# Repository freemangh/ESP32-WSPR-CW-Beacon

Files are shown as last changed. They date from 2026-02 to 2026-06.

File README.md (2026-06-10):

# ESP32 WSPR/FT8/CW Beacon

A standalone HF Beacon (WSPR, FT8 & CW) running on an ESP32.
It uses the ESP32's internal APLL (Audio PLL) clocking the I2S bit clock (BCK), routed through the GPIO matrix to generate RF directly on a GPIO pin. Because the APLL's native tuning step (~19 Hz at 14 MHz) is far coarser than the WSPR/FT8 tone spacing, a background task dithers the APLL fractional divider (software fractional-N synthesis) so the average frequency lands exactly on the requested tone.

## Features
- **WSPR Beacon**: Transmits standard WSPR Type 1 messages on the 20m band (14.0956 MHz).
- **FT8 Beacon**: Transmits `CQ CALL GRID` on 14.074 MHz in four consecutive 15 s slots.
- **CW Identification**: Transmits Morse code ID (Callsign + Grid) once per cycle.
- **Precision Timing**: Syncs via NTP over WiFi to ensure perfect WSPR/FT8 slot timing.
- **Frequency Calibration**: PPM correction constant to compensate crystal error.
- **OLED Display**: Shows current status, time, and transmission progress.
- **Direct RF Output**: Generates RF directly from a GPIO pin (default GPIO 27).
- **Power Output**: Approx. **10-15 mW (10-12 dBm)** direct drive.

## Transmission Schedule
The beacon runs a fixed 4-minute cycle, aligned to UTC:

| Minute (mod 4) | Mode | Start |
|---|---|---|
| 0–1 | WSPR (110.6 s) | :01 |
| 2 | FT8 (4 slots)  | :01, :16, :31, :46 |
| 3 | CW ID | :10 |

## Hardware Required
1. **ESP32 Development Board** (ESP32-WROOM-32 or similar)
2. **SSD1306 OLED Display** (I2C)
3. **Low Pass Filter (LPF)** for 20m Band (Critical for harmonic suppression)
4. **Antenna** (tuned for 14 MHz)

## Wiring

| ESP32 Pin | Component | Function |
|---|---|---|
| **GPIO 27**| **RF Output** | Signal to LPF -> Antenna |
| GPIO 21 | OLED SDA  | I2C Data |
| GPIO 22 | OLED SCL  | I2C Clock|
| 5V / 3V3  | VCC | Power |
| GND | GND | Ground |

**Note**: The RF Output pin can be changed in `src/Config.h`.

## Optional Power Amplifier (Boost to ~250mW)
To increase power from ~10mW to ~250mW (24dBm), use a simple BS170 MOSFET amplifier.

**Schematic:**
```mermaid
graph LR
    GPIO((GPIO 27)) -- 100R --- G
    G -- 10k --- GND
    
    subgraph BS170
    G(Gate)
    D(Drain)
    S(Source)
    end
    
    S --- GND((GND))
    VCC((+5V)) -- 10uH Choke --- D
    D -- 100nF --- LPF((To LPF))
```
- **Q1**: BS170 or 2N7000 MOSFET
- **Choke**: 10uH RF Choke (RFC)
- **C_Block**: 100nF Ceramic
- **R_Gate**: 100 ohm (Series), 10k (Pulldown)

## Low Pass Filter (LPF)
The output is a square wave. You **MUST** use a Low Pass Filter before connecting an antenna to prevent interference on higher harmonics.

**Schematic (20m / 14MHz):**
```mermaid
graph LR
    IN((RF IN)) -- L1 --- J1
    J1 -- L2 --- J2
    J2 -- L3 --- ANT((ANT))
    
    IN -- C1 --- G1((GND))
    J1 -- C2 --- G2((GND))
    J2 -- C3 --- G3((GND))
    ANT -- C4 --- G4((GND))
```
- **L1, L3**: 12 turns (~0.6 uH) on T37-6
- **L2**: 14 turns (~0.7 uH) on T37-6
- **C1, C4**: 470 pF
- **C2, C3**: 1000 pF

## Configuration
`src/Config.h` is gitignored (it contains your WiFi credentials). Create it from the template and configure your station:
```bash
cp src/Config.h.example src/Config.h
```
```cpp
#define WIFI_SSID "YOUR_SSID"
#define WIFI_PASS "YOUR_PASSWORD"
#define CALLSIGN "N0CALL"          // Your Callsign
#define GRID_LOCATOR "AA00aa"      // Your Grid Square
#define FREQ_CORRECTION_PPM 0.0    // Crystal error correction (see below)
#define RF_PIN 27                  // Output Pin
```

### Frequency Calibration
Devboard crystals are typically off by 10–20 ppm, which is 150–300 Hz at 14 MHz — enough to land outside the 200 Hz WSPR window. Measure the actual carrier with an SDR during a transmission and set the correction:

```
measured 14095750 Hz vs requested 14095600 Hz -> +150 Hz error
FREQ_CORRECTION_PPM = -offset_hz / freq_mhz = -150.0 / 14.0956 = -10.6
```

## Build & Upload
This project uses **PlatformIO**.

1. Clone the repository.
2. Open in VSCode with PlatformIO extension.
3. Create and edit `src/Config.h` (see Configuration).
4. Run **Upload**:
   ```bash
   pio run -t upload
   ```
5. Monitor output:
   ```bash
   pio device monitor
   ```

## Verifying with an SDR
- Tune an SDR (e.g. HackRF with gqrx/SDR++) to 14.0956 MHz in USB/CW mode and watch the waterfall during minutes 0–1 of the cycle. Expect the carrier within a few hundred Hz of nominal until you calibrate `FREQ_CORRECTION_PPM`.
- To verify decodes, feed the SDR audio into WSJT-X (WSPR mode on 20m, or FT8 during minute 2).
- **Never connect the beacon output to the SDR input with a cable directly**: +10 dBm is at the absolute maximum input rating of a HackRF. Receive over the air, or use at least 30 dB of attenuation.
- Note: VHF/UHF FM handhelds (e.g. AnyTone AT-D878UV) cannot receive this beacon — 14 MHz is outside their frequency range, and an FM receiver cannot demodulate a CW carrier anyway.

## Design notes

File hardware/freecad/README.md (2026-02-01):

# FreeCAD Beacon Assembly

This directory contains resources to generate a 3D Assembly of the ESP32 Beacon in FreeCAD.

## How to use
1. Open **FreeCAD**.
2. Go to **View -> Panels -> Python Console** (Ensure it is visible).
3. Open the `beacon_assembly.py` file in a text editor.
4. Copy the entire content of `beacon_assembly.py`.
5. Paste it into the **Python Console** in FreeCAD and press Enter.

## Result
The script will generate a new document named `Beacon_Assembly` containing:
- The PCB Substrate (Green)
- ESP32 Development Board (Generic representation)
- OLED Display
- SMA Connector
- LPF Components (Inductors and Capacitors)

You can then export this as STEP or STL for enclosure design.

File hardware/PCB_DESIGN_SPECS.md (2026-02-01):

# PCB Design Specifications - ESP32 WSPR Beacon

## 1. Schematic Connections

### Main Controller (ESP32 Dev Board)
- **3V3**: Connect to Display VCC.
- **GND**: Connect to Display GND, LPF Ground, RF Connector Ground.
- **GPIO 21 (SDA)**: Connect to Display SDA.
- **GPIO 22 (SCL)**: Connect to Display SCL.
- **GPIO 27**: **RF SOURCE**. Connect to LPF Input.

### Low Pass Filter (LPF) Network
*Note: Layout should be linear (Input -> L1 -> L2 -> L3 -> Output)*
1. **Input Node**:
   - Connect **ESP32 GPIO 27**.
   - Connect **C1 (470pF)** to GND.
   - Connect **L1 (0.6uH)** Pin 1.
2. **Node A (Between L1/L2)**:
   - Connect **L1** Pin 2.
   - Connect **C2 (1000pF)** to GND.
   - Connect **L2 (0.7uH)** Pin 1.
3. **Node B (Between L2/L3)**:
   - Connect **L2** Pin 2.
   - Connect **C3 (1000pF)** to GND.
   - Connect **L3 (0.6uH)** Pin 1.
4. **Output Node**:
   - Connect **L3** Pin 2.
   - Connect **C4 (470pF)** to GND.
   - Connect **RF Connector** Center Pin.

### Peripherals
- **OLED Display**:
  - VCC -> 3V3
  - GND -> GND
  - SDA -> GPIO 21
  - SCL -> GPIO 22

## 2. Layout Guidelines
1. **RF Trace**: Keep the trace from GPIO 27 to LPF and LPF to Antenna short and thick (e.g., 0.5mm+).
2. **Ground Plane**: Use a solid Ground Pour on bottom (and top if possible). Stitch them with vias.
3. **LPF**:
   - Place Capacitors (C1-C4) close to the inductors.
   - Ensure specific Ground Vias for each capacitor component to the ground plane.
   - Keep the LPF components (Inductors) slightly spaced to avoid magnetic coupling (or place at 90 degrees if very close).
4. **Antenna Connector**: Place at board edge. Ensure good grounding on the shield pins.

## 3. Mounting
- Add M3 mounting holes at corners.
- Dimensions recommended: 70mm x 50mm (Approx).

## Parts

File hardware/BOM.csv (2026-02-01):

Item | Reference | Qty | Description | Value | Footprint
1 | U1 | 1 | ESP32 Development Board | ESP32-WROOM-32 | Module:ESP32_DevBoard
2 | DSP1 | 1 | OLED Display I2C | SSD1306 0.96 inch | Connector_PinHeader_2.54mm:PinHeader_1x04_P2.54mm_Vertical
3 | J1 | 1 | RF Output Connector | SMA / BNC | Connector_Coaxial:SMA_Amphenol_132203_Vertical
4 | C1,C4 | 2 | Ceramic Capacitor (C0G/NP0) | 470pF / 50V | Capacitor_SMD:C_0805_2012Metric
5 | C2,C3 | 2 | Ceramic Capacitor (C0G/NP0) | 1000pF / 50V | Capacitor_SMD:C_0805_2012Metric
6 | L1,L3 | 2 | Inductor (Toroid T37-6) | 0.6uH (12 turns) | Inductor_THT:L_Toroid_Vertical_L10.0mm_W5.0mm_P5.08mm
7 | L2 | 1 | Inductor (Toroid T37-6) | 0.7uH (14 turns) | Inductor_THT:L_Toroid_Vertical_L10.0mm_W5.0mm_P5.08mm
8 | J2 | 1 | Power Connector (Optional if USB used) | 2-pin Screw Terminal | Connector_Phoenix_MC:PhoenixContact_MC_1,5_2-G-3.81_1x02_P3.81mm_Horizontal

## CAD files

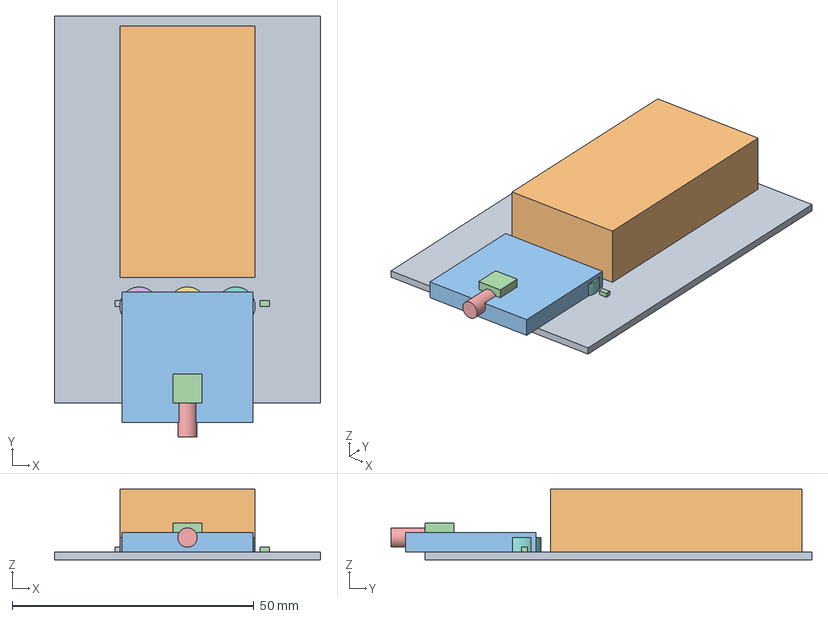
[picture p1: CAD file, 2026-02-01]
hardware/freecad/Beacon_Assembly.FCStd
55.0 x 87.0 x 14.6 mm
PCB
ESP32
OLED
SMA_Body
SMA_Pin
L1
L2
L3
C1
C2
C3
C4

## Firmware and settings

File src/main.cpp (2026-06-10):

#include <Adafruit_GFX.h>
#include <Adafruit_SSD1306.h>
#include <Arduino.h>
#include <JTEncode.h>
#include <WiFi.h>
#include <Wire.h>
#include <time.h>

#include "Config.h"
#include "Radio.h"

// Objects
Adafruit_SSD1306 display(SCREEN_WIDTH, SCREEN_HEIGHT, &Wire, OLED_RESET);
JTEncode jtEncode;

// Global State
bool wifiConnected = false;
bool timeSynced = false;
bool isTransmittingWSPR = false;
bool isTransmittingCW = false;
bool isTransmittingFT8 = false;

// WSPR State
uint8_t tx_buffer[255]; // Encoded symbols (values 0-3)
int symbol_count = 0;
int current_symbol_index = 0;
unsigned long time_last_symbol = 0;
const unsigned long WSPR_SYMBOL_DURATION_US = 682667;
const double WSPR_TONE_SPACING = 1.4648;

// FT8 State
uint8_t tx_buffer_ft8[79];
int ft8_symbol_count = 0;
int current_ft8_index = 0;
unsigned long time_last_ft8 = 0;
const unsigned long FT8_SYMBOL_DURATION_US = 160000;
const double FT8_TONE_SPACING_VAL = 6.25;

// CW State
const char *cw_message = CALLSIGN " " GRID_LOCATOR;
int cw_char_index = 0;
int cw_element_index = 0; // Index within the morse string for a char
unsigned long cw_last_element_time = 0;
const int CW_WPM = 20;
const int CW_DOT_MS = 1200 / CW_WPM;
bool cw_tone_on = false;
String current_morse_char = "";

// Morse Code Table (Simple A-Z, 0-9)
const char *morse_table[] = {
    ".-",    // A
    "-...",  // B
    "-.-.",  // C
    "-..",   // D
    ".",     // E
    "..-.",  // F
    "--.",   // G
    "....",  // H
    "..",    // I
    ".---",  // J
    "-.-",   // K
    ".-..",  // L
    "--",    // M
    "-.",    // N
    "---",   // O
    ".--.",  // P
    "--.-",  // Q
    ".-.",   // R
    "...",   // S
    "-",     // T
    "..-",   // U
    "...-",  // V
    ".--",   // W
    "-..-",  // X
    "-.--",  // Y
    "--..",  // Z
    "-----", // 0
    ".----", // 1
    "..---", // 2
    "...--", // 3
    "....-", // 4
    ".....", // 5
    "-....", // 6
    "--...", // 7
    "---..", // 8
    "----."  // 9
};

const char *getMorse(char c) {
  if (c >= 'a' && c <= 'z')
    c -= 32; // To Upper
  if (c >= 'A' && c <= 'Z')
    return morse_table[c - 'A'];
  if (c >= '0' && c <= '9')
    return morse_table[c - '0' + 26];
  return ""; // Space or unknown
}

// Epoch values below this mean the system clock has not been set yet
const time_t TIME_VALID_EPOCH = 1600000000; // 2020-09-13

String formatUTC() {
  time_t now = time(nullptr);
  struct tm tmv;
  gmtime_r(&now, &tmv);
  char buf[20];
  snprintf(buf, sizeof(buf), "%04d-%02d-%02d %02d:%02d:%02d",
           tmv.tm_year + 1900, tmv.tm_mon + 1, tmv.tm_mday, tmv.tm_hour,
           tmv.tm_min, tmv.tm_sec);
  return String(buf);
}

void setupDisplay() {
  Wire.begin(I2C_SDA, I2C_SCL);
  if (!display.begin(SSD1306_SWITCHCAPVCC, 0x3C)) {
    Serial.println(F("SSD1306 allocation failed"));
    for (;;)
      ;
  }
  display.clearDisplay();
  display.setTextSize(1);
  display.setTextColor(SSD1306_WHITE);
  display.setCursor(0, 0);
  display.println("ESP32 Beacon");
  display.display();
}

void connectWiFi() {
  Serial.print("Connecting to WiFi: ");
  Serial.println(WIFI_SSID);
  display.println("Connecting WiFi...");
  display.display();

  WiFi.setAutoReconnect(true); // reconnect in the background if the AP drops
  WiFi.begin(WIFI_SSID, WIFI_PASS);

  int retries = 0;
  while (WiFi.status() != WL_CONNECTED && retries < 20) {
    delay(500);
    Serial.print(".");
    retries++;
  }

  if (WiFi.status() == WL_CONNECTED) {
    wifiConnected = true;
    Serial.println("\nWiFi Connected");
    Serial.println(WiFi.localIP());
    display.println("WiFi Connected!");
  } else {
    Serial.println("\nWiFi Failed");
    display.println("WiFi Failed :(");
  }
  display.display();
}

void syncTime() {
  if (!wifiConnected)
    return;

  Serial.println("Syncing Time...");
  display.println("Syncing NTP...");
  display.display();

  // Built-in SNTP: fully asynchronous, resyncs in the background (hourly by
  // default) and never blocks loop() — a failed NTP poll must not stall the
  // WSPR/FT8 symbol pacing.
  configTime(UTC_OFFSET * 3600, 0, NTP_SERVER);

  // Wait up to 10 s for the first sync; if it doesn't land, SNTP keeps
  // trying in the background and loop() picks it up when it arrives.
  for (int i = 0; i < 100 && time(nullptr) < TIME_VALID_EPOCH; i++)
    delay(100);

  if (time(nullptr) >= TIME_VALID_EPOCH) {
    timeSynced = true;
    Serial.println("Time Synced: " + formatUTC());
    display.println("Time Synced!");
  } else {
    Serial.println("NTP sync pending (will retry in background)");
    display.println("NTP pending...");
  }
  display.display();
}

void prepareWSPR() {
  Serial.println("Encoding WSPR message...");
  memset(tx_buffer, 0, sizeof(tx_buffer));
  jtEncode.wspr_encode(CALLSIGN, GRID_LOCATOR, TX_POWER_DBM, tx_buffer);
  symbol_count = 162;
  Serial.print("Symbols generated: ");
  Serial.println(symbol_count);
}

void prepareFT8() {
  Serial.println("Encoding FT8 message...");
  memset(tx_buffer_ft8, 0, sizeof(tx_buffer_ft8));
  // Format: CQ [CALL] [GRID4]
  char msg[20];
  // FT8 Grid is 4 chars. Remove last 2 chars from 6-char grid if needed.
  char grid4[5];
  strncpy(grid4, GRID_LOCATOR, 4);
  grid4[4] = '\0';

  snprintf(msg, sizeof(msg), "CQ %s %s", CALLSIGN, grid4);

  jtEncode.ft8_encode(msg, tx_buffer_ft8);
  ft8_symbol_count = 79;
  Serial.print("FT8 Symbols generated: ");
  Serial.println(ft8_symbol_count);
}

void setup() {
  Serial.begin(115200);
  setupDisplay();
  connectWiFi();
  syncTime();

  Radio::begin();
  if (ENABLE_WSPR)
    prepareWSPR();
  if (ENABLE_FT8)
    prepareFT8();
}

// --- WSPR Logic ---
void startWSPR() {
  isTransmittingWSPR = true;
  current_symbol_index = 0;
  time_last_symbol = micros();
  Serial.println("Starting WSPR TX");
  Radio::setFrequency(
      WSPR_FREQ_20M); // Base freq. Actual transmission adds tones.
}

void stopWSPR() {
  isTransmittingWSPR = false;
  Radio::disable();
  Serial.println("Stop WSPR TX");
}

void updateWSPR() {
  if (!isTransmittingWSPR)
    return;

  unsigned long now = micros();
  if (now - time_last_symbol >= WSPR_SYMBOL_DURATION_US) {
    time_last_symbol += WSPR_SYMBOL_DURATION_US;

    if (current_symbol_index < symbol_count) {
      uint8_t symbol = tx_buffer[current_symbol_index];
      double tone_freq = WSPR_FREQ_20M + (symbol * WSPR_TONE_SPACING);
      Radio::setFrequency(tone_freq);
      current_symbol_index++;
    } else {
      stopWSPR();
    }
  }
}

// --- FT8 Logic ---
void startFT8() {
  isTransmittingFT8 = true;
  current_ft8_index = 0;
  time_last_ft8 = micros();
  Serial.println("Starting FT8 TX");
  // Set initial freq (Base + Offset + Symbol 0 of GFSK)
  // Actually, we update it in the loop immediately, but setting it here primes
  // the PLL
  Radio::setFrequency(FT8_FREQ_20M + FT8_OFFSET_HZ);
}

void stopFT8() {
  isTransmittingFT8 = false;
  Radio::disable();
  Serial.println("Stop FT8 TX");
}

void updateFT8() {
  if (!isTransmittingFT8)
    return;

  unsigned long now = micros();
  if (now - time_last_ft8 >= FT8_SYMBOL_DURATION_US) {
    time_last_ft8 += FT8_SYMBOL_DURATION_US;

    if (current_ft8_index < ft8_symbol_count) {
      uint8_t symbol = tx_buffer_ft8[current_ft8_index];
      // FT8 uses 8-GFSK tones spaced by 6.25Hz
      double tone_freq =
          (FT8_FREQ_20M + FT8_OFFSET_HZ) + (symbol * FT8_TONE_SPACING_VAL);
      Radio::setFrequency(tone_freq);
      current_ft8_index++;
    } else {
      stopFT8();
    }
  }
}

// --- CW Logic ---
void startCW() {
  isTransmittingCW = true;
  cw_char_index = -1; // updateCW pre-increments before reading a char
  cw_element_index = 0;
  cw_last_element_time = millis();
  cw_tone_on = false;
  current_morse_char = ""; // Will trigger load of first char
  Serial.println("Starting CW ID");
}

void stopCW() {
  isTransmittingCW = false;
  Radio::disable();
  Serial.println("Stop CW ID");
}

void updateCW() {
  if (!isTransmittingCW)
    return;

  unsigned long now = millis();

  static unsigned long next_event_time = 0;
  static enum { CW_IDLE, CW_TONE, CW_SPACE } cw_state = CW_IDLE;

  if (now < next_event_time)
    return; // Wait

  // Event finished, what next?
  if (cw_state == CW_TONE) {
    Radio::disable();
    cw_state = CW_SPACE;
    next_event_time = now + CW_DOT_MS; // Intra-char space (1 unit)
    return;
  }

  // If we were in space (or idle), get next element
  if (cw_state == CW_SPACE || cw_state == CW_IDLE) {
    // Check if we need a new char
    if (cw_element_index >= current_morse_char.length()) {
      // Next char
      cw_char_index++;
      if (cw_char_index >= strlen(cw_message)) {
        stopCW();
        return;
      }

      char c = cw_message[cw_char_index];
      if (c == ' ') {
        // Word space (7 units). We already did 1 unit space after last char
        // keyup. So wait 6 more.
        cw_state = CW_SPACE;
        // Reset element index for next char
        cw_element_index = 0;
        current_morse_char = ""; // Mark as space
        next_event_time = now + (6 * CW_DOT_MS);
        return;
      } else {
        current_morse_char = String(getMorse(c));
        cw_element_index = 0;
        // Char space (3 units). We already did 1 unit. So wait 2 more.
        cw_state = CW_SPACE;
        next_event_time = now + (2 * CW_DOT_MS);
        return;
      }
    }

    // Output next element of current char
    char element = current_morse_char[cw_element_index++];
    // Transmit CW on WSPR freq (or close to it)
    Radio::setFrequency(WSPR_FREQ_20M);
    cw_state = CW_TONE;
    if (element == '.') {
      next_event_time = now + CW_DOT_MS;
    } else {
      next_event_time = now + (3 * CW_DOT_MS);
    }
  }
}

void loop() {
  // SNTP keeps the clock fresh in the background; just notice the first sync
  // in case it wasn't ready during setup
  if (!timeSynced && time(nullptr) >= TIME_VALID_EPOCH) {
    timeSynced = true;
    Serial.println("Time Synced: " + formatUTC());
  }

  // Scheduler
  // Schedule Cycle (4 minutes):
  // Min 0: WSPR Start (Even)
  // Min 1: WSPR Cont/End
  // Min 2: FT8 (4 slots: 00, 15, 30, 45)
  // Min 3: CW ID

  if (timeSynced && !isTransmittingWSPR && !isTransmittingCW &&
      !isTransmittingFT8) {
    time_t rawTime = time(nullptr);
    struct tm *ptm = gmtime(&rawTime);

    int currentMinute = ptm->tm_min;
    int currentSecond = ptm->tm_sec;
    int minuteInCycle = currentMinute % 4; // 0, 1, 2, 3

    // WSPR: Minute 0-1 (Start at 00:01)
    if (ENABLE_WSPR && minuteInCycle == 0 && currentSecond == 1) {
      startWSPR();
    }

    // FT8: Minute 2 (Slots: 00, 15, 30, 45)
    else if (ENABLE_FT8 && minuteInCycle == 2) {
      // Start at 01, 16, 31, 46 to allow 1s settling logic if needed, or stick
      // to 00 FT8 standard starts at :00, :15, :30, :45. We use :01, :16 etc
      // simply to ensure we didn't miss the second tick or conflict with loop
      // timing
      if (currentSecond == 1 || currentSecond == 16 || currentSecond == 31 ||
          currentSecond == 46) {
        startFT8();
      }
    }

    // CW: Minute 3 (Start at 00:10)
    else if (ENABLE_CW && minuteInCycle == 3 && currentSecond == 10) {
      startCW();
    }
  }

  if (isTransmittingWSPR)
    updateWSPR();
  if (isTransmittingFT8)
    updateFT8();
  if (isTransmittingCW)
    updateCW();

  // UI Update Loop (Low priority)
  static unsigned long lastPrint = 0;
  if (millis() - lastPrint > 1000) {
    lastPrint = millis();
    display.clearDisplay();
    display.setCursor(0, 0);
    display.println("ESP32 Beacon");
    display.println(formatUTC()); // UTC date + time, 19 chars fits one line

    // Serial Monitor Output (Headless Mode)
    Serial.print("[");
    Serial.print(formatUTC());
    Serial.print("] ");

    if (isTransmittingWSPR) {
      display.println(">> TX WSPR <<");
      display.print("Sym: ");
      display.print(current_symbol_index);
      display.print("/");
      display.println(symbol_count);

      Serial.print("TX WSPR | Sym: ");
      Serial.print(current_symbol_index);
      Serial.print("/");
      Serial.println(symbol_count);

    } else if (isTransmittingFT8) {
      display.println(">> TX FT8 <<");
      display.print("Sym: ");
      display.print(current_ft8_index);
      display.print("/");
      display.println(ft8_symbol_count);

      Serial.print("TX FT8 | Sym: ");
      Serial.print(current_ft8_index);
      Serial.print("/");
      Serial.println(ft8_symbol_count);

    } else if (isTransmittingCW) {
      display.println(">> TX CW <<");
      display.print("Msg: ");
      display.println(cw_message);

      Serial.print("TX CW | Msg: ");
      Serial.println(cw_message);

    } else {
      display.println(">> IDLE <<");

      // Find the next enabled TX event in the 4-minute cycle
      struct TxEvent {
        bool enabled;
        int second; // start offset within the cycle
        const char *name;
      };
      static const TxEvent events[] = {
          {ENABLE_WSPR, 0 * 60 + 1, "WSPR"}, {ENABLE_FT8, 2 * 60 + 1, "FT8"},
          {ENABLE_FT8, 2 * 60 + 16, "FT8"},  {ENABLE_FT8, 2 * 60 + 31, "FT8"},
          {ENABLE_FT8, 2 * 60 + 46, "FT8"},  {ENABLE_CW, 3 * 60 + 10, "CW"},
      };

      time_t rawTime = time(nullptr);
      struct tm *ptm = gmtime(&rawTime);
      int nowInCycle = (ptm->tm_min % 4) * 60 + ptm->tm_sec;

      const char *nextName = nullptr;
      int nextIn = 0;
      for (auto &e : events) {
        if (!e.enabled)
          continue;
        int wait = e.second - nowInCycle;
        if (wait <= 0)
          wait += 4 * 60;
        if (!nextName || wait < nextIn) {
          nextName = e.name;
          nextIn = wait;
        }
      }

      if (nextName) {
        display.print("Next: ");
        display.print(nextName);
        display.print(" in ");
        display.print(nextIn);
        display.print("s");

        Serial.print("IDLE | Next: ");
        Serial.print(nextName);
        Serial.print(" in ");
        Serial.print(nextIn);
        Serial.println("s");
      } else {
        display.print("All modes disabled");
        Serial.println("IDLE | All modes disabled");
      }
    }

    display.display();
  }
}

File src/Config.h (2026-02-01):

#pragma once

#include <Arduino.h>

// WiFi Configuration
// TODO: Move to WiFiManager or Web Interface
#define WIFI_SSID "YOUR_SSID"
#define WIFI_PASS "YOUR_PASSWORD"

// Beacon Configuration
#define CALLSIGN "N0CALL"
#define GRID_LOCATOR "AA00aa"
#define TX_POWER_DBM                                                           \
  10 // Not actually used for hardware control yet, just for WSPR encoding

// Frequency Configuration (WSPR Band: 20m)
#define WSPR_FREQ_20M 14095600ULL
#define WSPR_FREQ_40M 7038600ULL
#define TARGET_FREQ WSPR_FREQ_20M

// Hardware Configuration
#define RF_PIN 27 // Safe pin, avoiding Boot (0) or TX/RX (1/3)
#define I2C_SDA 21
#define I2C_SCL 22
#define OLED_RESET -1
#define SCREEN_WIDTH 128
#define SCREEN_HEIGHT 64

// NTP Configuration
#define NTP_SERVER "pool.ntp.org"
#define UTC_OFFSET 0

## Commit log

2026-02-01 Initial commit: ESP32 WSPR/CW Beacon firmware
2026-02-01 Update README with power output specs
2026-02-01 Add Amplifier Schematic to README
2026-02-01 Add Hardware Design: KiCad Project, BOM, FreeCAD Assembly
    [BOM.csv, Beacon_Assembly.FCStd, beacon.kicad_pcb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]
2026-06-10 Add FT8 mode, fix RF output path, make NTP non-blocking
    Major fixes and features:
    - FT8 beacon mode (CQ CALL GRID on 14.074 MHz, 4 slots in minute 2 of a
    4-minute WSPR/FT8/CW cycle)
    - RF path rewrite: GPIO matrix signal 224 (SIG_IN_FUNC224, an internal
    loopback) carried no clock, so the beacon never emitted RF. Route the
    APLL-driven I2S0 bit clock (I2S0O_BCK_OUT) to the RF pin instead, and
    add a 1 kHz sigma-delta dither task on the APLL SDM word so 1.46 Hz
    WSPR / 6.25 Hz FT8 tone spacing is reachable despite the ~19 Hz native
    APLL step. Add FREQ_CORRECTION_PPM for crystal calibration.
    - Replace polling NTPClient with built-in async SNTP: a failed NTP poll
    blocked loop() ~1 s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
    [Radio.cpp, main.cpp]
